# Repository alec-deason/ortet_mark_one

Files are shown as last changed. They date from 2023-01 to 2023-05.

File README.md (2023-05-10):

This is the electronics design and firmware for the Ortet Mark One MIDI controller.

## How to flash the firmware

In order to flash the firmware on the the controller's RP Pico you'll need to setup your rust environment by installing the `thumbv6m-none-eabi` target:
```
rustup target add thumbv6m-none-eabi
```

Then you will need `elf2uf2-rs` for building the UF2:
```
cargo install elf2uf2-rs
```

Then put the Pico into bootloader mode by holding the BOOTSEL button on the board while plugging it in to your computer. The board should mount as a USB drive at which point you can run:
```
cargo run --release
```

The project should build and install itself onto the Pico, then the Pico should reboot and present as a USB MIDI device named `Ortet MIDI Controller`.

For more information see the rp_pico documentation: https://github.com/rp-rs/rp-hal-boards/tree/main/boards/rp-pico

## License

This work is licensed under either of

- Apache License, Version 2.0 ([LICENSE-APACHE](LICENSE-APACHE) or
  <http://www.apache.org/licenses/LICENSE-2.0>)
- MIT license ([LICENSE-MIT](LICENSE-MIT) or <http://opensource.org/licenses/MIT>)

at your option.

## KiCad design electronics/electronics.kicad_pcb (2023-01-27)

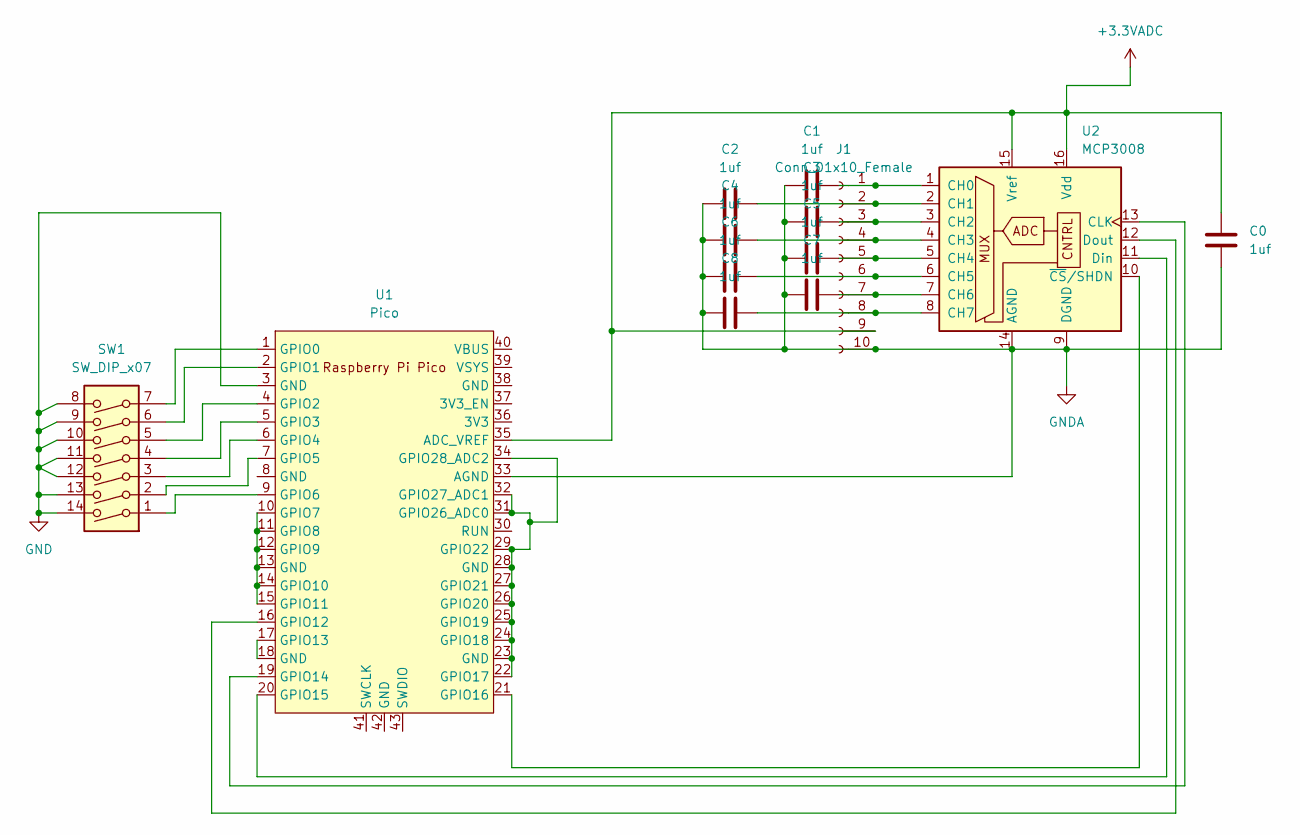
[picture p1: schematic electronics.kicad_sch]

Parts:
C0, C1, C2, C3, C4, C5, C6, C7, C8: 1uf; C_0603_1608Metric
J1: Conn_01x10_Female; PinHeader_2x05_P2.54mm_Vertical_SMD
SW1: SW_DIP_x07; DIP-14_W7.62mm_SMDSocket_SmallPads
U1: Pico; RPi_Pico_SMD_TH
U2: MCP3008; SOIC-16_3.9x9.9mm_P1.27mm

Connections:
+3.3VADC: C0.1, J1.9, U1.35 (ADC_VREF), U2.15 (Vref), U2.16 (Vdd)
GND: SW1.8, SW1.9, SW1.10, SW1.11, SW1.12, SW1.13, SW1.14, U1.3 (GND)
GNDA: C0.2, C1.1, C2.1, C3.1, C4.1, C5.1, C6.1, C7.1, C8.1, J1.10, U1.33 (AGND), U2.9 (DGND), U2.14 (AGND)
unnamed: C1.2, J1.1, U2.1 (CH0)
unnamed: C2.2, J1.2, U2.2 (CH1)
unnamed: C3.2, J1.3, U2.3 (CH2)
unnamed: C4.2, J1.4, U2.4 (CH3)
unnamed: C5.2, J1.5, U2.5 (CH4)
unnamed: C6.2, J1.6, U2.6 (CH5)
unnamed: C7.2, J1.7, U2.7 (CH6)
unnamed: C8.2, J1.8, U2.8 (CH7)
unnamed: SW1.1, U1.9 (GPIO6)
unnamed: SW1.2, U1.7 (GPIO5)
unnamed: SW1.3, U1.6 (GPIO4)
unnamed: SW1.4, U1.5 (GPIO3)
unnamed: SW1.5, U1.4 (GPIO2)
unnamed: SW1.6, U1.2 (GPIO1)
unnamed: SW1.7, U1.1 (GPIO0)
unnamed: U1.10 (GPIO7), U1.11 (GPIO8), U1.12 (GPIO9), U1.13 (GND), U1.14 (GPIO10), U1.15 (GPIO11)
unnamed: U1.16 (GPIO12), U2.12 (Dout)
unnamed: U1.17 (GPIO13), U1.18 (GND)
unnamed: U1.19 (GPIO14), U2.13 (CLK)
unnamed: U1.20 (GPIO15), U2.11 (Din)
unnamed: U1.21 (GPIO16), U2.10 (~CS/SHDN)
unnamed: U1.22 (GPIO17), U1.23 (GND), U1.24 (GPIO18), U1.25 (GPIO19), U1.26 (GPIO20), U1.27 (GPIO21), U1.28 (GND), U1.29 (GPIO22), U1.31 (GPIO26_ADC0), U1.32 (GPIO27_ADC1), U1.34 (GPIO28_ADC2)

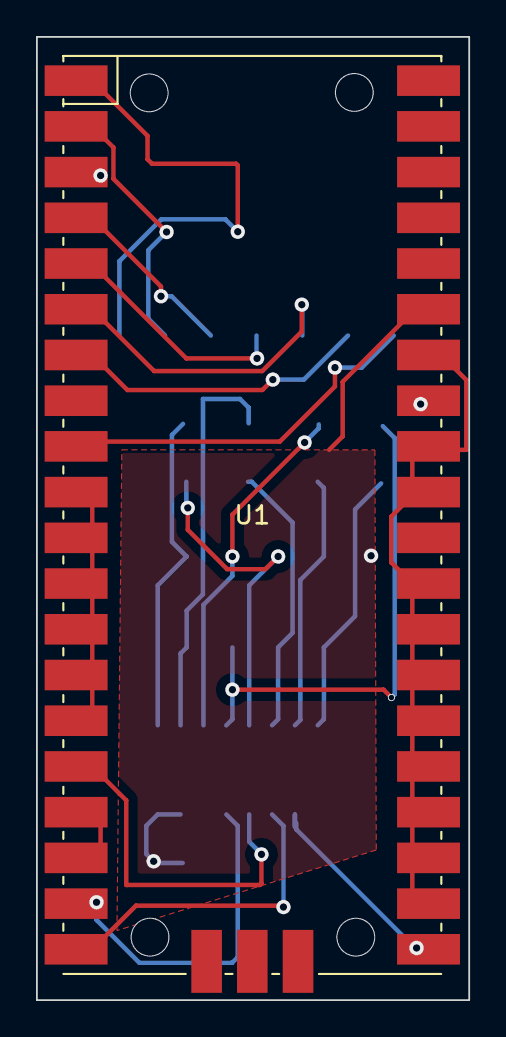
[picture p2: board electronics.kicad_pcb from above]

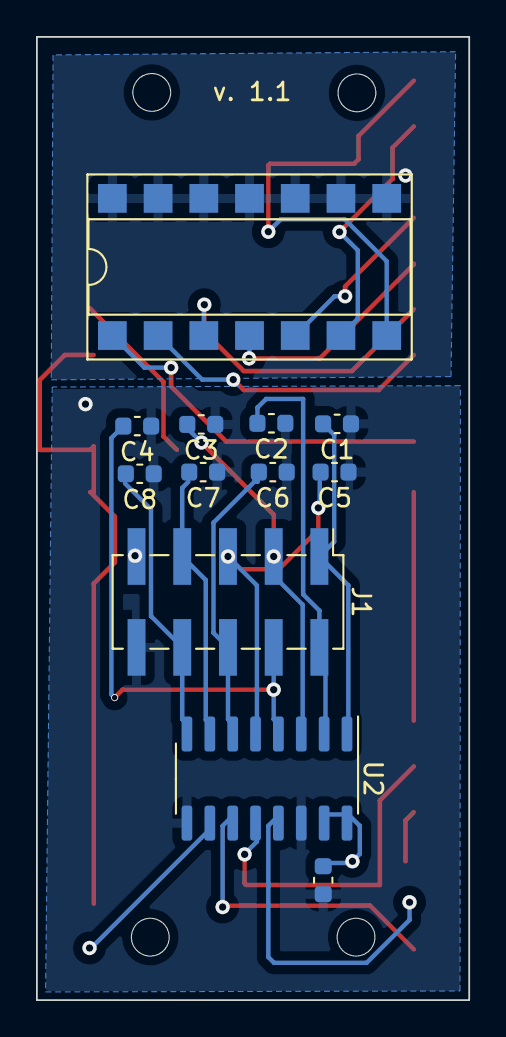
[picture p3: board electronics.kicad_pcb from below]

Board: 2 copper layers, 24.0 x 53.5 mm, 13 parts (12 on the bottom side), 25 nets.

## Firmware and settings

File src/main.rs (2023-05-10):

//! Firmware for the Ortet Mark One series of midi controllers.

#![deny(warnings)]
#![no_std]
#![no_main]

use adc_mcp3008::Mcp3008;
use embedded_hal::digital::v2::{InputPin, OutputPin};
use fugit::RateExtU32;
use panic_halt as _;
use rp2040_hal::usb::UsbBus;
use rp_pico::entry;
use rp_pico::hal::{self, gpio::pin::bank0::Gpio16, pac, prelude::*};
use usb_device::{class_prelude::UsbBusAllocator, device::UsbVidPid, prelude::UsbDeviceBuilder};
use usbd_midi::{
    data::{
        byte::{from_traits::FromClamped, u7::U7},
        midi::{
            channel::Channel,
            message::{control_function::ControlFunction, Message},
        },
        usb::constants::USB_AUDIO_CLASS,
        usb_midi::{cable_number::CableNumber, usb_midi_event_packet::UsbMidiEventPacket},
    },
    midi_device::MidiClass,
};

type SPI = rp2040_hal::Spi<rp2040_hal::spi::Enabled, pac::SPI1, 8>;
type CS = rp2040_hal::gpio::Pin<Gpio16, rp2040_hal::gpio::Output<rp2040_hal::gpio::PushPull>>;

struct Controller {
    knob_values: [[u8; 2]; 8],

    midi_channel: Channel,
}

impl Controller {
    fn new(midi_channel: Channel) -> Self {
        Controller {
            knob_values: [[0,0]; 8],
            midi_channel,
        }
    }

    fn process_knobs(&mut self, adc: &mut Mcp3008<SPI, CS>, midi: &mut MidiClass<UsbBus>) -> Result<(), ()> {
        for i in 0..4 {
            let channel = match i {
                0 => adc_mcp3008::Channels8::CH0,
                1 => adc_mcp3008::Channels8::CH1,
                2 => adc_mcp3008::Channels8::CH2,
                3 => adc_mcp3008::Channels8::CH3,
                4 => adc_mcp3008::Channels8::CH4,
                5 => adc_mcp3008::Channels8::CH5,
                6 => adc_mcp3008::Channels8::CH6,
                7 => adc_mcp3008::Channels8::CH7,
                _ => unreachable!(),
            };
            let r = adc.read_channel(channel).map_err(|_| ())?;
            let r1 = (r / 8) as u8;
            if r1 != self.knob_values[i][0] && r1 != self.knob_values[i][1] {
                // We keep two samples worth of history here because sometimes there is just enough noise
                // to cause the value to bounce repeatedly between two adjacent values and we want to
                // suppress that without reducing over all sensitivity.
                self.knob_values[i][1] = self.knob_values[i][0];
                self.knob_values[i][0] = r1;
                let midi_message = UsbMidiEventPacket::from_midi(
                    CableNumber::Cable0,
                    Message::ControlChange(
                        self.midi_channel,
                        ControlFunction(U7::from_clamped(i as u8)),
                        U7::from_clamped(r1),
                    ),
                );
                midi.send_message(midi_message).map_err(|_| ())?;
            }
        }
        Ok(())
    }

    fn process(&mut self, adc: &mut Mcp3008<SPI, CS>, midi: &mut MidiClass<UsbBus>) -> Result<(), ()> {
        self.process_knobs(adc, midi)
    }
}

#[entry]
fn main() -> ! {
    let mut pac = pac::Peripherals::take().unwrap();
    let core = pac::CorePeripherals::take().unwrap();

    let mut watchdog = hal::Watchdog::new(pac.WATCHDOG);

    let clocks = hal::clocks::init_clocks_and_plls(
        rp_pico::XOSC_CRYSTAL_FREQ,
        pac.XOSC,
        pac.CLOCKS,
        pac.PLL_SYS,
        pac.PLL_USB,
        &mut pac.RESETS,
        &mut watchdog,
    )
    .ok()
    .unwrap();
    let mut delay = cortex_m::delay::Delay::new(core.SYST, clocks.system_clock.freq().to_Hz());

    let sio = hal::Sio::new(pac.SIO);

    let pins = rp_pico::Pins::new(
        pac.IO_BANK0,
        pac.PADS_BANK0,
        sio.gpio_bank0,
        &mut pac.RESETS,
    );

    let usb_bus = UsbBusAllocator::new(hal::usb::UsbBus::new(
        pac.USBCTRL_REGS,
        pac.USBCTRL_DPRAM,
        clocks.usb_clock,
        true,
        &mut pac.RESETS,
    ));

    let mut midi = MidiClass::new(&usb_bus, 1, 0).unwrap();

    let mut usb_dev = UsbDeviceBuilder::new(&usb_bus, UsbVidPid(0x16c0, 0x5e4))
        .product("Ortet MIDI Controller")
        .device_class(USB_AUDIO_CLASS)
        .build();

    let _spi_sclk = pins.gpio14.into_mode::<hal::gpio::FunctionSpi>();
    let _spi_mosi = pins.gpio15.into_mode::<hal::gpio::FunctionSpi>();
    let _spi_miso = pins.gpio12.into_mode::<hal::gpio::FunctionSpi>();
    let chip_enable = pins.gpio16.into_push_pull_output();

    let spi = hal::Spi::<_, _, 8>::new(pac.SPI1);
    let spi = spi.init(
        &mut pac.RESETS,
        clocks.peripheral_clock.freq(),
        1.MHz(),
        &adc_mcp3008::MODE,
    );
    let mut adc = adc_mcp3008::Mcp3008::new(spi, chip_enable).unwrap();

    let mut channel = 0;
    channel += pins.gpio6.into_pull_up_input().is_low().unwrap() as u8;
    channel += pins.gpio5.into_pull_up_input().is_low().unwrap() as u8 * 2;
    channel += pins.gpio4.into_pull_up_input().is_low().unwrap() as u8 * 4;
    channel += pins.gpio3.into_pull_up_input().is_low().unwrap() as u8 * 8;
    channel += pins.gpio2.into_pull_up_input().is_low().unwrap() as u8 * 16;
    channel += pins.gpio1.into_pull_up_input().is_low().unwrap() as u8 * 32;
    channel += pins.gpio0.into_pull_up_input().is_low().unwrap() as u8 * 64;
    let midi_channel = Channel::try_from(channel.min(15)).unwrap_or(Channel::Channel1);

    let mut controller = Controller::new(midi_channel);

    let mut led_pin = pins.led.into_push_pull_output();
    let _ = led_pin.set_high();

    loop {
        usb_dev.poll(&mut [&mut midi]);
        if controller.process(&mut adc, &mut midi).is_err() {
            let _ = led_pin.set_low();
            delay.delay_ms(100);
            let _ = led_pin.set_high();
        }
        delay.delay_ms(1);
    }
}
